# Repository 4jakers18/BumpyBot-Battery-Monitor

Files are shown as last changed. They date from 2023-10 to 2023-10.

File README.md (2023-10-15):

# Bumpybot-Battery-Monitor
Battery Monitoring Device designed for BumpyBot utilizing ROS-Serial and a I2C TFT Display

Designed by Jacob Tomczeszyn for The Human-Centered Robotics Laboratory at The University of Texas at Austin
  
 Designed for Adafruit QT Py M0, Reads ADC values at A2 and A3 expecting divided voltage.
 Displays undivided voltage and other derived values on Adafruit 1.12" I2C display.
 
 Acts as a ROS publisher utilizing rosserial over a USB connection the Bumpybot Computer.
 
For `BatteryState` ROS message documentation see [here](http://docs.ros.org/en/api/sensor_msgs/html/msg/BatteryState.html).

## Hardware 

### PCB
Designed in Kicad 7, project and gerber files are included in the ```PCB``` folder. Note that the gerber is "panelized" in a 4x4 configuration, so if sent to fabrication, it will be made as one panel with 16 individual PCB's seperated by V-cuts. Designed around JLCPCB fabrication capabilities. 

Also note that [BOM.csv](PCB/BOM.csv) is not formatted for KiCad, and is missing [U2](#u2-pololu-5v-500ma-step-down-voltage-regulator-d24v5f5). 

[Click here for the schematic PDF](PCB/BumpyBotBatteryMonitorkicad_pro.pdf)

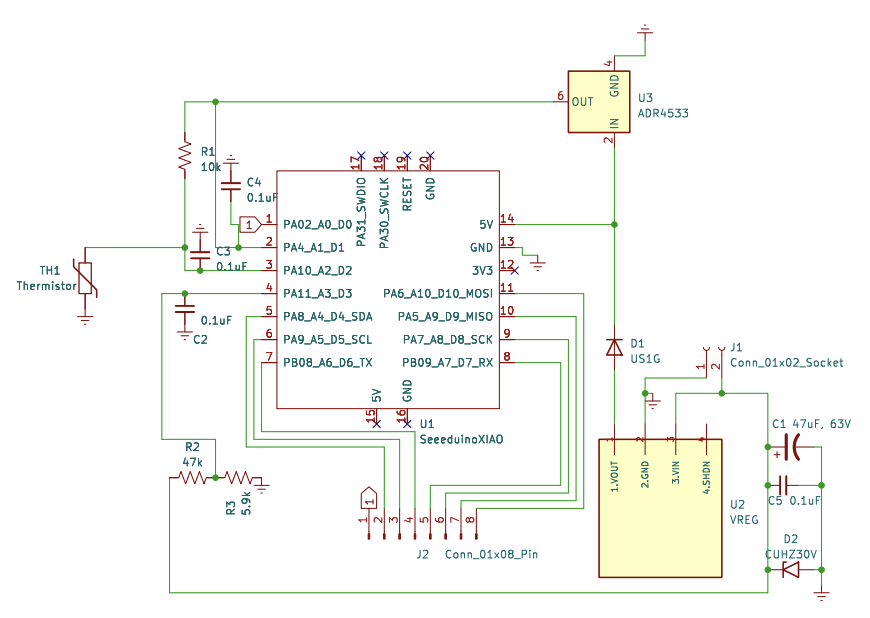
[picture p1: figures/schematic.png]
Schematic

<table>
  <tr>
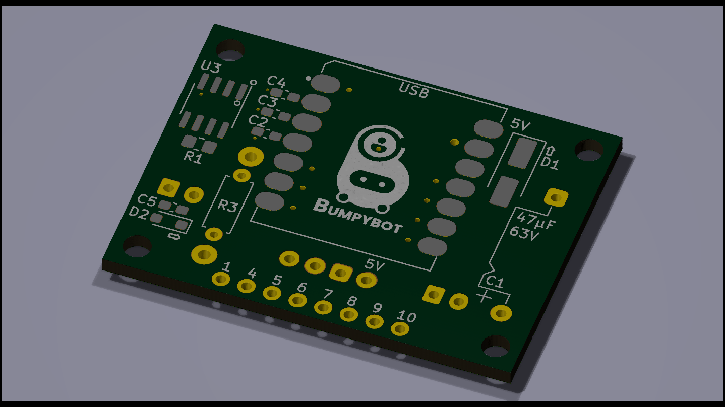
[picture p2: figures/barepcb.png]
barepcb
    <td></td>
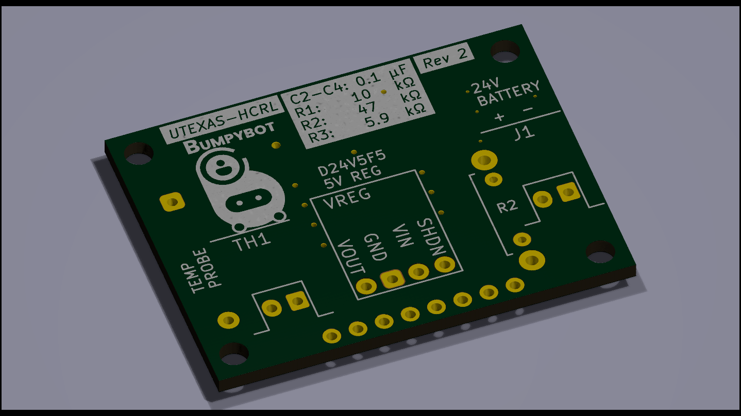
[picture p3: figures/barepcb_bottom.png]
barepcb bottom
    <td></td>  </tr>
  <tr>
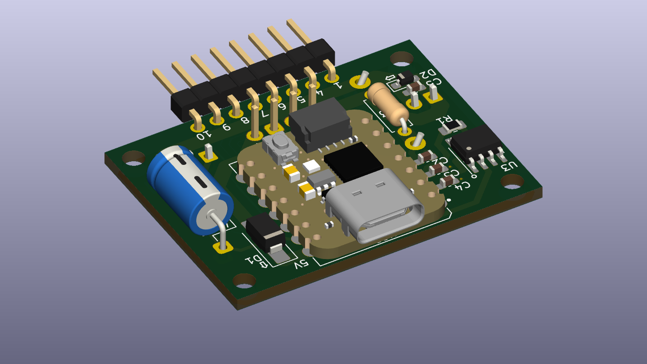
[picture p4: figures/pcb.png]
pcb
    <td></td>
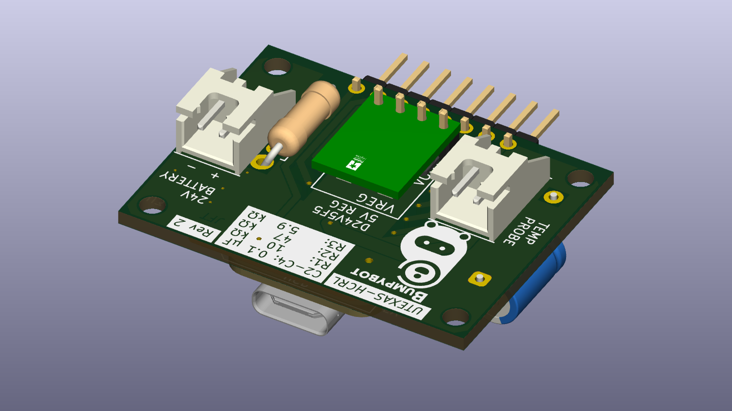
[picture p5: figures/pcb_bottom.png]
pcb bottom
    <td></td>
  </tr>
</table>
TH1 is the JST connector in the schematic/PCB, see below for the actual device.

### Adafruit QT Py - SAMD21 Dev Board with STEMMA QT
  - https://www.adafruit.com/product/4600
  - SeeedStudio Xiao footprint, soldered to PCB via castellated pads
### Adafruit Monochrome 1.12" 128x128 OLED Graphic Display
  - https://www.adafruit.com/product/5297
  - Connected to the Qt Py via the I2C STEMMA QT port
  - Attached to the pcb via M2.5 standoffs.
### *TH1*: Littelfuse USP10982 NTC Thermistor
- https://www.digikey.com/en/products/detail/littelfuse-inc/USP10982/2651606
- 10Kohm at ~25 degrees Celcius
- Beta (K): 3892k
### *U2*: Pololu 5V, 500mA Step-Down Voltage Regulator D24V5F5
- https://www.pololu.com/product/2843/specs
- U2 on the PCB Schematic, THT Soldered to the PCB, *NOT INCLUDED IN BOM FILE.*

## Software Setup & Dependencies

[Follow instructions on setting up Arduino IDE for Adafruit SAMD21 boards](https://learn.adafruit.com/adafruit-qt-py/arduino-ide-setup)
    - This should be optional, as [arduino-cli is already installed](#compiling-and-upload-using-arduino-cli) and setup on the Bumpybot computer. This project relies on the base Arduino library, so keep that in mind if you wish to compile using a different tool.

#### From here, you should be okay to clone this reposiitory and use as-is, but if you wish to setup the dependencies seperately:

- Either use the precompiled [ros_lib library in this repository](libraries/ros_lib) or follow [instructions on compiling yourself](http://wiki.ros.org/rosserial_arduino).
- [Adafruit GFX Arduino Library](https://github.com/adafruit/Adafruit-GFX-Library)
- [Adafruit SH110X Display Driver Library](https://github.com/adafruit/Adafruit_SH110x)

#### If you wish to setup the dependencies yourself, Please see the following notes:

### ros_lib/ArduinoHardware.h
If you self-compile ros_lib, you must modify ros_lib/ArduinoHardware.h to enable ROSserial compatibility with the Adafruit QT Py M0.
Add the following lines between the first `#enddif` and the next `#if defined` near the top of the file.
The precompiled and modified [ros_lib](libraries/ros_lib) is already included in this repository, you can just use it instead of compiling it yourself.

```
#if 1
class ArduinoHardware {
  public:
    ArduinoHardware()
    {
      baud_ = 250000;
    }  
    void setBaud(long baud){
      this->baud_= baud;
    }
    int getBaud(){return baud_;}
    void init(){
      Serial.begin(baud_);
      while(!Serial.available());
    }
    int read(){return Serial.read();};
    void write(uint8_t* data, int length){
      for(int i=0; i<length; i++)
        Serial.write(data[i]);
    }
    unsigned long time(){return millis();}
  protected:
    long baud_;
};
#else
```
### Adafruit_SH110X/spash.h 
I've created a custom startup image of the Bumpybot Logo for the display.
This custom file is not necessary but is included in this repository.

## Compiling and Upload using arduino-cli
`arduino-cli` should already be set up properly already to allow for easy compilation and upload.

To compile without uploading, run:
```
arduino-cli compile -v -b adafruit:samd:adafruit_qtpy_m0 BumpyBot_AFM0_BAT_TEMP_ROSSERIAL.ino 
```
To upload, first ensure that that the monitor is connected to the Bumpybot computer via usb, and run:
```
arduino-cli board list
```
You should something like the following:
```
Port         Protocol Type              Board Name                 FQBN                           Core         
             serial   Serial Port       Unknown                                                                
/dev/ttyACM0 serial   Serial Port (USB) Adafruit QT Py M0 (SAMD21) adafruit:samd:adafruit_qtpy_m0 adafruit:samd
/dev/ttyACM1 serial   Serial Port (USB) Unknown                                                                
/dev/ttyS0   serial   Serial Port       Unknown                                                                
/dev/ttyS1   serial   Serial Port       Unknown                                                                
/dev/ttyS4   serial   Serial Port       Unknown                                                                
/dev/ttyS5   serial   Serial Port       Unknown                                                                
/dev/ttyS6   serial   Serial Port       Unknown                                                                
/dev/ttyUSB0 serial   Serial Port (USB) Unknown            
```
Noting the port, ```/dev/ttyACM0``` in this case, run the following to initiate the upload:

```
arduino-cli upload -p /dev/ttyACM0 -v -b adafruit:samd:adafruit_qtpy_m0 BumpyBot_AFM0_BAT_TEMP_ROSSERIAL.ino 
```
(Replacing ```/dev/ttyACM0``` with the correct port if necessary)

It should take a moment to upload, if you get any upload-specific error, attempt the upload again, if that doesnt work, double-press the RESET button on the QT Py board in the monitor, and try again.

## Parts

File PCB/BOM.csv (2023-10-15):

Reference | Value | Footprint | Manufacturer Part # | Digikey Part #
C1 | 47uF, 63V | Capacitor_THT:CP_Radial_Tantal_D6.0mm_P2.50mm | EY1J470MP51007E | 4191-EY1J470MP51007ECT-ND
C2-C5 | 0.1uF. 100V | Capacitor_SMD:C_0603_1608Metric_Pad1.08x0.95mm_HandSolder | CL10B104KC8NNNC | 1276-6807-1-ND
D1 | US1G | Diode_SMD:D_SMA_Handsoldering | US1G_R1_00001 | 3757-US1G_R1_00001CT-ND
D2 | CUHZ30V | Diode_SMD:D_SOD-323_HandSoldering | CUHZ30V,H3F | 264-CUHZ30VH3FCT-ND
R1 | 10k | Resistor_SMD:R_0805_2012Metric_Pad1.20x1.40mm_HandSolder | RNCP0805FTD10K0 | RNCP0805FTD10K0CT-ND
R2 | 47k | Resistor_THT:R_Axial_DIN0411_L9.9mm_D3.6mm_P12.70mm_Horizontal | CMF6047K000BEBF | CMF6047K000BEBF-ND
R3 | 5.9k | Resistor_THT:R_Axial_DIN0207_L6.3mm_D2.5mm_P7.62mm_Horizontal | YR1B5K9CC | 1712-YR1B5K9CCCT-ND
U1 | Adafruit QT PY SAMD21 | SeeedStudioXiao | 4600 | 1528-4600-ND
U3 | ADR4533 | Package_SO:SOIC-8_3.9x4.9mm_P1.27mm | ADR4533ARZ-R7 | 505-ADR4533ARZ-R7CT-ND

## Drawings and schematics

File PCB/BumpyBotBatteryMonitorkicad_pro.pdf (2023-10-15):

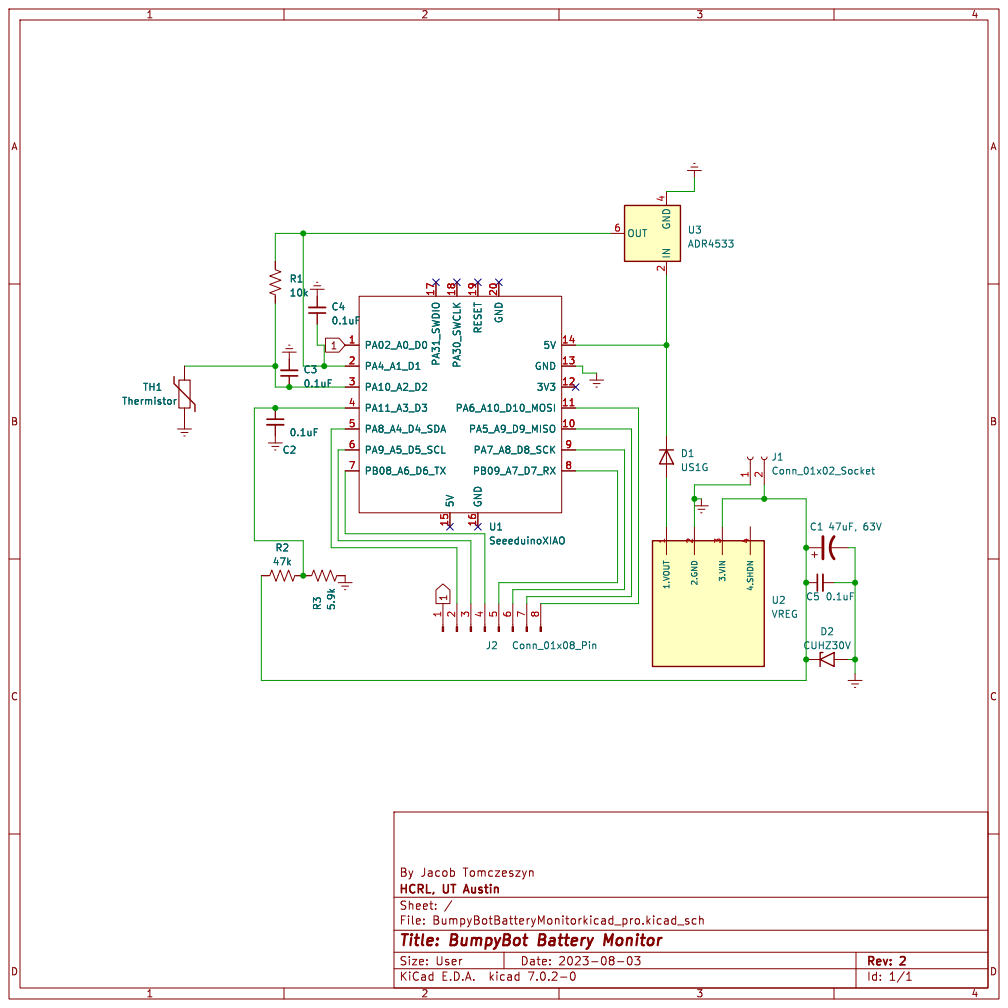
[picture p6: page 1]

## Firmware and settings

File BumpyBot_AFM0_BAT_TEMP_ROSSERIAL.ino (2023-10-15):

/********************************************************************
 * 
 * Written by Jacob Tomczeszyn
 * Designed for BumpyBot
 * The Human Centered Robotics Laboratory
 * The University of Texas at Austin
 * 
 Designed for Adafruit QT Py M0, Reads ADC values at A2 and A3 expecting divided voltage.
 Displays undivided voltage and other derived values on Adafruit 1.12" I2C display.
 Acts as a ROS publisher utilizing rosserial, 

 See README.md for more info.
*******************************************************************/

#include "helper_functions.h"
//ROSserial


bool rosInit = false;

//Graphics & Display

#define SCREEN_WIDTH 128  // OLED display width, in pixels
#define SCREEN_HEIGHT 128 // OLED display height, in pixels
#define OLED_RESET -1     // can set an oled reset pin if desired
Adafruit_SH1107 display = Adafruit_SH1107(SCREEN_WIDTH, SCREEN_HEIGHT, &Wire, OLED_RESET, 1000000, 100000);

//ADC & Averaging
const int VoltageInput = A3;
const int TempInput = A2;
const int maxAdcValue = 4095;  // Maximum ADC value for 12-bit ADC
const float referenceVoltage = 3.299; // Reference voltage
const float R1 = 47000; // R1 Approximate Value
const float R2 = 5901.82; // R2 Actual Value (only one need be tuned, only the ratio is important)
const unsigned int sampleInterval = 100;  // Sample every 100ms
const unsigned int averagePeriod = 3000; // Average over 3 seconds

float Voltage_Divided = 0.0;
float Voltage_Measured = 0.0;
float Cap_Percent;
bool lowbattery = 0; //Low Battery Flag

bool noADC = 0; // Set true to use TEST values for display and rosserial


//Thermistor Calculation
const int THERMISTORNOMINAL = 10000; // resistance at 25 degrees C
const int TEMPERATURENOMINAL = 25; // temp. for nominal resistance (almost always 25 C)
const int BCOEFFICIENT = 3892; // The beta coefficient of the thermistor (usually 3000-4000)
const int SERIESRESISTOR = 10000; // the value of other thermistor resistor



float Temp_C = 0.0;
float Temp_F = 0.0;

//Charging State Detection
const float CHARGING_VOLTAGE_DIFFERENCE = 0.5;
const int CHARGING_STOP_THRESHOLD = 2;
float previousVoltage = 0.00;
bool isCharging = false;
int chargingStopCounter = 0; 



void setup()   {
  analogReference(AR_EXTERNAL);  //Set A1 as Reference (connected to the 3.3V reg.)
  analogReadResolution(12); //enable 12-bit ADC on SAMD21 board
  
  pinMode(VoltageInput, INPUT_PULLUP); //"_PULLUP" neccesary for M0 boards
  pinMode(TempInput, INPUT_PULLUP);


/*Display Setup*/
  delay(250); //Wait for the OLED to power up
  display.setRotation(1);
  display.begin(0x3D, true); //I2C Address 0x3D is default
  display.display(); //Show image buffer (Bumpybot Logo) on the display hardware.
/*End Display Setup*/
  delay(2000); //Display glorius project logo for 2 seconds
}

void loop() {
  if(noADC == 1){
    Voltage_Measured = 27.54;
    Temp_C = 31.5;
    }
    
  else{
  float avgVoltage_Divided, avgTempRes;
  getAveragedReadings(avgVoltage_Divided, avgTempRes);
  Voltage_Measured = (avgVoltage_Divided / (R2/(R1+R2)));
  detectChargingStatus();
  Temp_C = steinhart(avgTempRes);
  }
  
  Temp_F = 32 + (Temp_C * 1.8); //Fahrenheit Conversion (optional, use either Temp_F or Temp_C in draw() if you wish);
  
  Cap_Percent = Battery_Capacity(Voltage_Measured);
  
  if(Cap_Percent >= 0 && Cap_Percent <= 5){ // Low Battery Warning flag
    lowbattery = 1;
    }
  else{
    lowbattery = 0;
    }
  draw();
  ROSmsg_init_write();
}

//Function to display values on OLED
void draw(void) {
  if(noADC == 1){
    delay(averagePeriod); }
  int offset;
  int capacity_test = 75;
  display.clearDisplay();
  display.setRotation(2);
  display.setTextSize(2);      // Normal 1:1 pixel scale
  display.setTextColor(SH110X_WHITE); // Draw white text
  display.setCursor(0, 0);     // Start at top-left corner
  display.cp437(true);         // Use full 256 char 'Code Page 437' font
  display.invertDisplay(false);
  
//Low Battery Display Warning

   
  if(isCharging == true){
  display.println("~Charging~");
  display.println(" "); 
  }
  else if(lowbattery == true){
  display.invertDisplay(true);
  display.println("  LOW");
  display.println("BATTERY"); 
  } 

  else{
  display.println("BumpyBot");
  display.println(" "); 
  }

  display.print(" ");
  if(Voltage_Measured < 1){
    display.print("???");
  }
  else{
  display.print(Voltage_Measured,2);
  display.println("V");
  }
  display.println(" ");
  
  if(isCharging == true){
  display.print("  ");
  display.write(0x18); //up arrow symbol on capacity percent
  display.print(" ");
  Cap_Percent -= 3;
  }
  
  else if(lowbattery == true){
  display.print("  ");
  display.write(0x21); // '!' on capacity percent
  display.print(" "); 
  }
  
  else{
  display.print(" "); 
  }
    if(Voltage_Measured < 1){
    display.println("???");
  }
  else{
  display.print(Cap_Percent,0);
  display.println("%");
  }
  display.println(" "); 
  display.print(" ");
  display.print(Temp_F, 1);
  display.println("F");
//replace the above two lines with the following two lines to use Celcius on the display
 // display.print(Temp_C, 1); 
 // display.println("C");
 
//Cap_Percent offset
if(Cap_Percent >= 0){
offset = 100 - Cap_Percent;
}
else{
  offset = 95;
}
//Battery Visual
//vertical
display.fillRoundRect(101,  18,  19,  4,  3,  SH110X_WHITE); 
display.drawRoundRect(93,  20,  35,  108,  10,  SH110X_WHITE);
display.drawRoundRect(94,  21,  33,  106,  8,  SH110X_WHITE);
display.fillRoundRect(98,  24+offset,  25,  100-offset,  5,  SH110X_WHITE);

//horizontal WIP
//display.fillRoundRect(18, 101,  4, 19,  3,  SH110X_WHITE); 
//display.drawRoundRect(20, 93,  35,  108,  10,  SH110X_WHITE);
//display.drawRoundRect(94,  21,  33,  106,  8,  SH110X_WHITE);
//display.fillRoundRect(98,  24+offset,  25,  100-offset,  5,  SH110X_WHITE);
  


  display.display();
  delay(100);
}

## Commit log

2023-09-10 Revert "Delete .vscode directory"
    This reverts commit a06a53e8940a0de8e9e1a2cddf60cc5e4b9b288e.
    new file: .vscode/arduino.json
    new file: .vscode/c_cpp_properties.json
    new file: .vscode/settings.json
2023-09-10 deleted: .vscode/arduino.json deleted: .vscode/c_cpp_properties.json deleted: .vscode/settings.json
2023-10-15 Adding PCB files
    [BOM.csv, BumpyBotBatteryMonitorkicad_pro.kicad_sch]
2023-10-15 deleted: PANELGERB.zip renamed: BOM.csv -> PCB/BOM.csv renamed: BumpyBotBatteryMonitorkicad_pro.kicad_pcb -> PCB/BumpyBotBatteryMonitorkicad_pro.kicad_pcb renamed: BumpyBotBatteryMonitorkicad_pro.kic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
    [BOM.csv, BumpyBotBatteryMonitorkicad_pro.kicad_sch]
2023-10-15 modified: README.md new file: figures/barepcb.png new file: figures/barepcb_bottom.png new file: figures/pcb.png new file: figures/pcb_bottom.png new file: figures/schematic.png
